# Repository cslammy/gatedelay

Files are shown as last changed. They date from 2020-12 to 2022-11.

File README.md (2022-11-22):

# gatedelay
I needed to delay and extend gate and trigger signals for modular synthesis and logic applications.
Uses Arduino Promini and arduino sketch. 
Allows Delay the entire signal, or just the beginning of the signal while keeping release elements intact.

For more detail please see the blog post here--there are links to earlier posts while the build was being worked out.

https://audiodiwhy.blogspot.com/2019/12/gate-delay-part-iii-works.html

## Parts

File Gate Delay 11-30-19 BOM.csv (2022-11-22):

Part | Value | Device | Package | Description | POPULARITY | SPICEPREFIX | TP_SIGNAL_NAME | Column1
78L05 | 5V | 78LXX | 78LXX | VOLTAGE REGULATOR
C3 | 10uF | CPOL-USE2.5-6 | E2,5-6 | POLARIZED CAPACITOR, American symbol
C4 | 47uF | CPOL-USE2.5-7 | E2,5-7 | POLARIZED CAPACITOR, American symbol
D1 | 1N5404 | 1N4148DO35-10 | DO35-10 | DIODE | 21
D3 |  | WIREPAD2,15/1,0 | 2,15/1,0 | Wire PAD connect wire on PCB | 2
D4 | 4148 | 1N4148DO35-7 | DO35-7 | DIODE | 58
D5 |  | WIREPAD2,15/1,0 | 2,15/1,0 | Wire PAD connect wire on PCB | 2
D6 | NZX5V1 | ZENER.2 | DO41-2
D7 | NZX5V1 | ZENER.2 | DO41-2
DELAYCV |  | 35RAPC2AV | 35RAPCVAV | Switchcraft 35RAPC2AV jack
DELAYLED |  | LED3MM | LED3MM | LED
DELAYPOT | 100K | POTS9MM_VERT | 9MM_VERT
DLYCV_CHK |  | 3,17/1,3 | 3,17/1,3 | THROUGH-HOLE PAD | 3
DOUT |  | 35RAPC2AV | 35RAPCVAV | Switchcraft 35RAPC2AV jack
GATEIN |  | 35RAPC2AV | 35RAPCVAV | Switchcraft 35RAPC2AV jack
GATEINLED |  | LED3MM | LED3MM | LED
IC1 | TL072D | TL072D | SO08 | OP AMP
IC2 | TL072_SMD | TL072_SMD | SO08 | Generic Dual Op Amp
LENGTHCV |  | 35RAPC2AV | 35RAPCVAV | Switchcraft 35RAPC2AV jack
LENGTHPOT | 100K | POTS9MM_VERT | 9MM_VERT
R1 | 10K | R-US_0204/5 | 0204/5 | RESISTOR, American symbol | 18 | R
R2 | 10K' | R-US_0204/5 | 0204/5 | RESISTOR, American symbol | 18 | R
R3 | 10K | R-US_0204/5 | 0204/5 | RESISTOR, American symbol | 18 | R
R4 | 10K | R-US_0204/5 | 0204/5 | RESISTOR, American symbol | 18 | R
R5 | 10k | R-US_0207/10 | 0207/10 | RESISTOR, American symbol
R6 | 10k | R-US_0204/5 | 0204/5 | RESISTOR, American symbol
R7 | 1K | R-US_0207/7 | 0207/7 | RESISTOR, American symbol
R8 | 4.7K | R-US_0204/5 | 0204/5 | RESISTOR, American symbol | 18 | R
R9 | 10K | R-US_0204/5 | 0204/5 | RESISTOR, American symbol | 18 | R
R10 | 10K' | R-US_0204/5 | 0204/5 | RESISTOR, American symbol | 18 | R
R11 | 10K | R-US_0204/5 | 0204/5 | RESISTOR, American symbol | 18 | R
R12 | 10K | R-US_0204/5 | 0204/5 | RESISTOR, American symbol | 18 | R
R13 | 1K | R-US_0204/7 | 0204/7 | RESISTOR, American symbol
R14 | 4.7K | R-US_0204/5 | 0204/5 | RESISTOR, American symbol | 18 | R
R16 | 1K | R-US_0204/7 | 0204/7 | RESISTOR, American symbol
R17 | 1K | R-US_0204/7 | 0204/7 | RESISTOR, American symbol
R18 | 1K | R-US_0207/15 | 0207/15 | RESISTOR, American symbol | 0 | R
S1 | . | ALCOSWTT11 | ALCOSWTT11 | TINY SWITCH ON - MOM
S2 | . | ALCOSWTT11 | ALCOSWTT11 | TINY SWITCH ON - MOM
T1 | 2N3904 | 2N3904 | TO92 | NPN TRANSISTOR | 27
T2 | 2N3904 | 2N3904 | TO92 | NPN TRANSISTOR | 27
T5 | 2N3904 | 2N3904 | TO92 | NPN TRANSISTOR | 27
T6 | 2N3904 | 2N3904 | TO92 | NPN TRANSISTOR | 27
U$1 | PRO-MINI | PRO-MINI | PRO-MINI | Arduion Pro Mini Clone V1.0

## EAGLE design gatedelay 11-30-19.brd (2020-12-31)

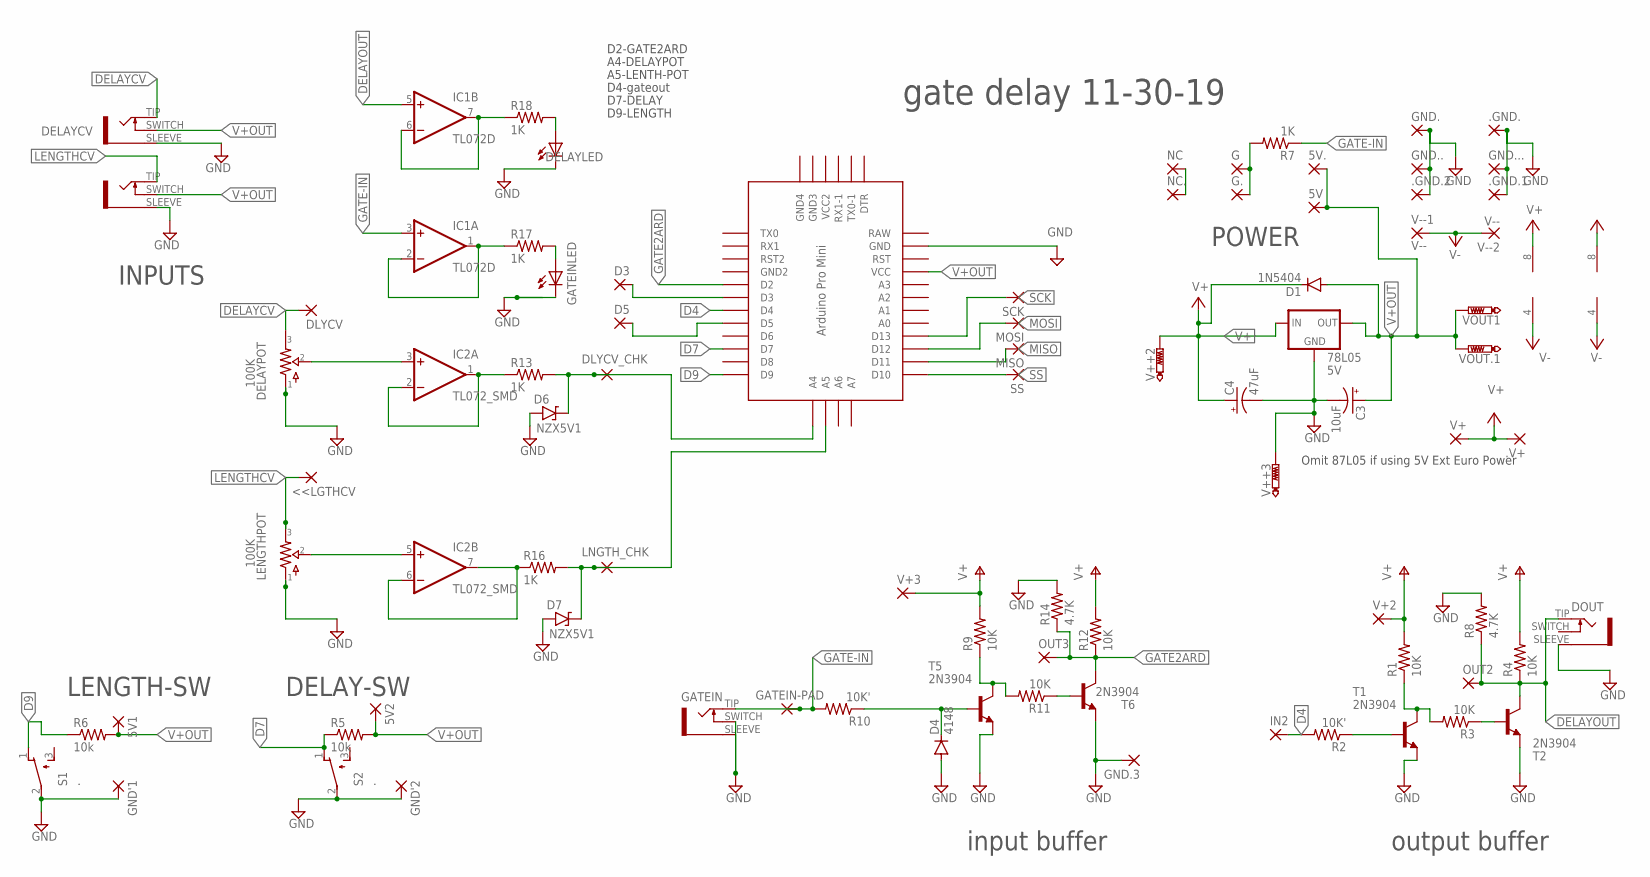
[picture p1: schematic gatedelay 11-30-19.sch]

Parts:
5V, 5V., .GND., .GND.1, .GND.2, .V+: 1,6/0,8
5V1, 5V2: WIREPAD2,54/0,9; 2,54/0,9
78L05: 5V; 78LXX
<<LGTHCV: 3,17/1,3
C3: 10uF; E2,5-6
C4: 47uF; E2,5-7
D1: 1N5404; DO35-10
D3, D5: WIREPAD2,15/1,0; 2,15/1,0
D4: 4148; DO35-7
D6, D7: NZX5V1; DO41-2
DELAYCV: 35RAPC2AV; 35RAPCVAV
DELAYLED: LED3MM
DELAYPOT: 100K; 9MM_VERT
DLYCV: WIREPAD1,6/0,9; 1,6/0,9
DLYCV_CHK: 3,17/1,3
DOUT: 35RAPC2AV; 35RAPCVAV
G, G.: 1,6/0,8
GATEIN: 35RAPC2AV; 35RAPCVAV
GATEIN-PAD: WIREPAD1,6/0,9; 1,6/0,9
GATEINLED: LED3MM
GND'1, GND'2: WIREPAD2,54/0,9; 2,54/0,9
GND., GND.., GND...: 1,6/0,8
GND.3: WIREPAD1,6/0,9; 1,6/0,9
IC1: TL072D; SO08
IC2: TL072_SMD; SO08
IN2: WIREPAD1,6/0,9; 1,6/0,9
LENGTHCV: 35RAPC2AV; 35RAPCVAV
LENGTHPOT: 100K; 9MM_VERT
LNGTH_CHK: 3,17/1,3
MISO: WIREPAD1,6/0,9; 1,6/0,9
MOSI: WIREPAD1,6/0,9; 1,6/0,9
NC, NC.: 1,6/0,8
OUT2, OUT3: WIREPAD1,6/0,9; 1,6/0,9
R1, R3, R4, R9, R11, R12: 10K; 0204/5
R2, R10: 10K'; 0204/5
R5: 10k; 0207/10
R6: 10k; 0204/5
R7: 1K; 0207/7
R8, R14: 4.7K; 0204/5
R13, R16, R17: 1K; 0204/7
R18: 1K; 0207/15
S1, S2: .; ALCOSWTT11
SCK: WIREPAD1,6/0,9; 1,6/0,9
SS: WIREPAD1,6/0,9; 1,6/0,9
T1, T2, T5, T6: 2N3904; TO92
U$1: PRO-MINI
V+: 1,6/0,8
V+2, V+3: WIREPAD1,6/0,9; 1,6/0,9
V++2, V++3: PTR1PAD1-13Y; P1-13Y
V--1, V--2: V--; 1,6/0,8
VOUT1, VOUT.1: PTR1PAD1-13Y; P1-13Y

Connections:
D4: IN2.1, R2.2, U$1.D4
D7: R5.1, S2.1 (O), U$1.D7
D9: R6.1, S1.1 (O), U$1.D9
DELAYCV: DELAYCV.TIP (2), DELAYPOT.3, DLYCV.1
DELAYOUT: DOUT.TIP (2), IC1.5 (+IN), OUT2.1, R4.1, R8.1, T2.1 (C)
GATE2ARD: OUT3.1, R12.1, R14.1, T6.1 (C), U$1.D2
GATE-IN: GATEIN.TIP (2), GATEIN-PAD.1, IC1.3 (+IN), R7.1, R10.2
GND: 78L05.GND, .GND..1, .GND.1.1, .GND.2.1, C3.-, C4.-, D4.A, D6.A, D7.A, DELAYCV.SLEEVE (1), DELAYLED.K (C), DELAYPOT.1, DOUT.SLEEVE (1), GATEIN.SLEEVE (1), GATEIN.SWITCH (3), GATEINLED.K (C), GND'1.1, GND'2.1, GND..1, GND.3.1, GND...1, GND....1, LENGTHCV.SLEEVE (1), LENGTHPOT.1, R8.2, R14.2, S1.2, S2.2, T1.3 (E), T2.3 (E), T5.3 (E), T6.3 (E), U$1.GND, V++3.TP
LENGTHCV: <<LGTHCV.1, LENGTHCV.TIP (2), LENGTHPOT.3
MISO: MISO.1, U$1.D11
MOSI: MOSI.1, U$1.D12
unnamed: D5.1, U$1.D5
unnamed: R2.1, T1.2 (B)
unnamed: R1.1, R3.2, T1.1 (C)
unnamed: R3.1, T2.2 (B)
unnamed: G.1, G..1, R7.2
unnamed: D3.1, U$1.D3
unnamed: NC.1, NC..1
unnamed: D4.C, R10.1, T5.2 (B)
unnamed: R9.1, R11.2, T5.1 (C)
unnamed: R11.1, T6.2 (B)
unnamed: D6.C, DLYCV_CHK.1, R13.2, U$1.A4
unnamed: DELAYPOT.2, IC2.3 (+IN)
unnamed: IC2.1 (OUT), IC2.2 (-IN), R13.1
unnamed: IC2.5 (+IN), LENGTHPOT.2
unnamed: IC2.6 (-IN), IC2.7 (OUT), R16.1
unnamed: D7.C, LNGTH_CHK.1, R16.2, U$1.A5
unnamed: GATEINLED.A, R17.2
unnamed: IC1.1 (OUT), IC1.2 (-IN), R17.1
unnamed: IC1.6 (-IN), IC1.7 (OUT), R18.1
unnamed: DELAYLED.A, R18.2
RAW: U$1.RAW
SCK: SCK.1, U$1.D13
SS: SS.1, U$1.D10
V+: 78L05.IN, .V+.1, C4.+, D1.C, IC1.8 (V+), IC2.8 (V+), R1.2, R4.2, R9.2, R12.2, V+.1, V+2.1, V+3.1, V++2.TP
V+OUT: 5V.1, 5V1.1, 5V2.1, 5V..1, 78L05.OUT, C3.+, D1.A, DELAYCV.SWITCH (3), LENGTHCV.SWITCH (3), R5.2, R6.2, U$1.VCC, VOUT1.TP, VOUT.1.TP
V-: IC1.4 (V-), IC2.4 (V-), V--1.1, V--2.1

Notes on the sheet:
POWER
DELAY-SW
LENGTH-SW
gate delay 11-30-19
output buffer
input buffer
D7-DELAY
D9-LENGTH
D4-gateout
A5-LENTH-POT
A4-DELAYPOT
D2-GATE2ARD
INPUTS
Omit 87L05 if using 5V Ext Euro Power

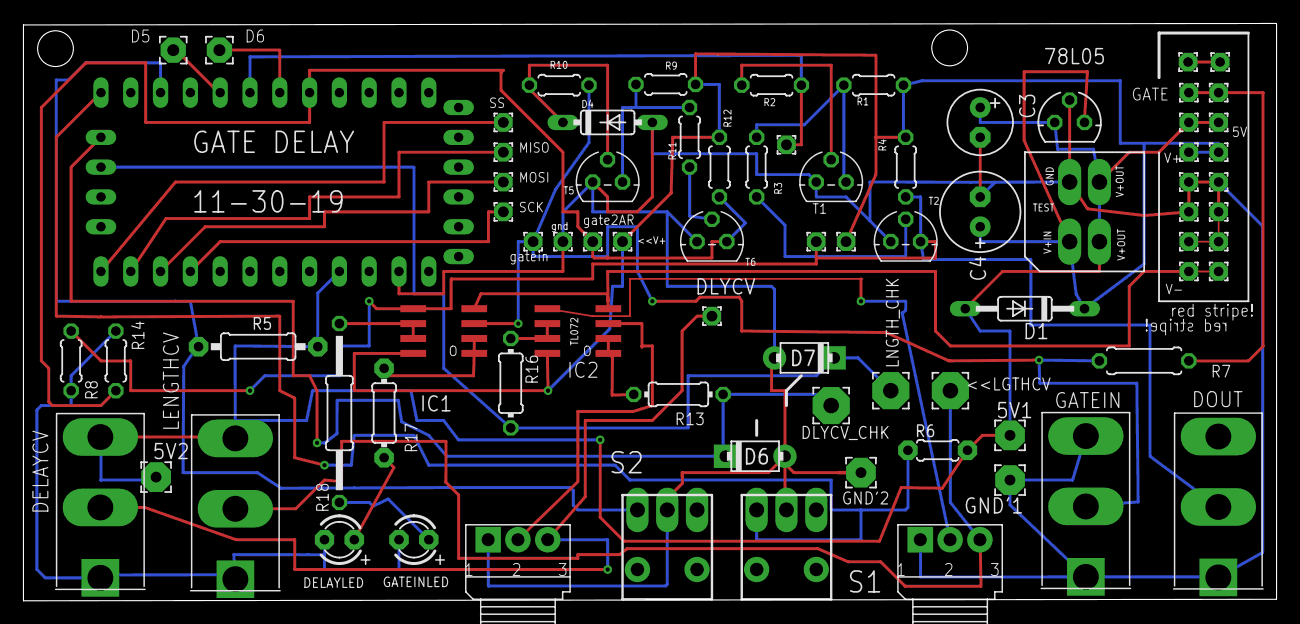
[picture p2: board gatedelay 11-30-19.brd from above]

Board: 2 copper layers, 106.8 x 49.2 mm, 82 parts (0 on the bottom side), 36 nets.

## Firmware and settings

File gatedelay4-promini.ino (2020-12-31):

const int GATEIN_PIN = 9;
const int GATESTATUS_PIN = 13;
int LENGTH_PIN = A0;
int DELAY_PIN = A1;

int CYCLE = 0;

int SKIP_DELAY = 0;
int SKIP_LENGTH = 0;

const int GATEOUT_PIN = 5;
const int EOGL_PIN = 2;  // length pot
const int EOGD_PIN = 3;   // delay pot

boolean EOGL_SW = HIGH;
boolean EOGD_SW = HIGH;
boolean GATEIN = LOW;
boolean GATEIN2 = LOW;
boolean GATEIN3 = LOW;
boolean GATESTATUS = LOW;
int x = 0;

unsigned long EOGL = 0;  //value of EOGL pot must be UL compared to time
unsigned long EOGD = 0;  // value of EOGD pot, ditto.


//timer variables
unsigned long begin_delay=0;
unsigned long begin_length=0;
unsigned long current_delay = 0;
unsigned long current_length = 0;
unsigned long test_delay = 0;
unsigned long test_length =0;

void setup() {
  // put your setup code here, to run once:
pinMode(GATEIN_PIN,INPUT);
pinMode(DELAY_PIN,INPUT);
pinMode(LENGTH_PIN,INPUT);
pinMode(EOGL_PIN,INPUT);
pinMode(EOGD_PIN,INPUT);



pinMode(GATESTATUS_PIN,OUTPUT);
pinMode(GATEOUT_PIN,OUTPUT);

digitalWrite(GATEOUT_PIN,LOW);

Serial.begin(9600);


} // end setup





void getstatus() {
    
    GATESTATUS = digitalRead(GATEIN_PIN);
    if (GATESTATUS == HIGH)
      {
        digitalWrite(GATESTATUS_PIN,HIGH);
      }
     else
      { 
        digitalWrite(GATESTATUS_PIN,LOW); 
      }
}  // end getstatus ()




void loop() 

{
//Serial.println("*****BEGINNING MAIN LOOP!*****")  ;



GATEIN = digitalRead(GATEIN_PIN);
delay(3);

//Serial.println("==========================CYCLE===========================");
//Serial.println(CYCLE);

if (GATEIN == LOW)
   {
    CYCLE = 0;

   }
   
if ((GATEIN == HIGH) && (CYCLE < 2 ))

      {
      CYCLE++;
      
      getstatus();
      begin_delay = millis();
      EOGD = 100;
      test_delay = 0;


/*
           Serial.println("OUTSIDE EOGD WHILE");
           Serial.println ("OUTSIDE test_delay is:");
           Serial.println (test_delay);
           Serial.println ("OUTSIDE EOGD is:");
           Serial.println (EOGD);
*/
   
      while ((EOGD > test_delay) && (SKIP_DELAY == 0)) 
           {
            getstatus();
           
            digitalWrite(GATEOUT_PIN,LOW);
            EOGD = (analogRead(DELAY_PIN) * 10);
            delay(3);
            current_delay = millis();
            test_delay = current_delay - begin_delay;    
      

     /*

           Serial.println("****INSIDE EOGD WHILE****");
           Serial.println ("INSIDE testdelay value is:");
           Serial.println (test_delay);
           Serial.println ("INSIDE EODG value is:");
           Serial.println (EOGD);
*/
           
  

          // check for EOGD_SW high and gate low.If that's the case skip rest of delay cycle.
          GATEIN2 = digitalRead(GATEIN_PIN);
          EOGD_SW = digitalRead(EOGD_PIN);


          if ((EOGD_SW == HIGH) && (SKIP_DELAY == 0) && (GATEIN2 == LOW))
              { 
                Serial.println("you are in SKIP delay");
               SKIP_DELAY = 5;
              }


          Serial.print("EOGD_SW value:  ");
          Serial.println(EOGD);
          Serial.print("SKIP_DELAY value:  ");
          Serial.println(SKIP_DELAY);
          Serial.print("GATEIN2 value:  ");
          Serial.println(GATEIN2);
          
    
                
           } // end EODG while 
         

         digitalWrite(GATEOUT_PIN,HIGH);    
           
 //DELAY IS OVER, GATE IS HIGH, NOW MOVE ON TO LENGTH  
          
          
          begin_length = millis();
          EOGL = 100;
          test_length = 0;
  
           /*
           Serial.println("OUTSIDE EOGL WHILE");
           Serial.println ("testlength is:");
           Serial.println (test_length);
           Serial.println ("EOGL is:");
           Serial.println (EOGL);
          */
 while ((EOGL > test_length)  && (SKIP_LENGTH == 0))
           {
            getstatus();
             EOGL = (analogRead(LENGTH_PIN) * 10);
            delay(3);   
             current_length = millis();      
            test_length = current_length - begin_length;        

           /*
           Serial.println ("INSIDE testlength is:");
           Serial.println (test_length);
           Serial.println ("INSIDE EOGL is:");
           Serial.println (EOGL);
           */
             // check status of EOGL switch and GATE  
  
        
// check for EOGL_SW high and gate low.If that's the case skip rest of length cycle.
          GATEIN3 = digitalRead(GATEIN_PIN);
          EOGL_SW = digitalRead(EOGL_PIN);
          if ((EOGL_SW == HIGH) && (SKIP_LENGTH == 0) && (GATEIN3 == LOW))
              { 
               SKIP_LENGTH = 5;
              Serial.println("You are in SKIP_LENGTH");
              }
           

             }           //end EOGL while

              digitalWrite(GATEOUT_PIN,LOW);
              delay(3);
              getstatus();
              delay(3);


      }    // end main loop IF 
         else
         {
   //      Serial.println("----------------GATE IS OFF---------------");
         digitalWrite(GATEOUT_PIN,LOW);
         
         // once it's off, stay off dammit!
         
         CYCLE ++;
         if (CYCLE > 6)
         {
          CYCLE = 2;
         }
         }

SKIP_DELAY = 0;
SKIP_LENGTH = 0;
GATEIN2 = HIGH;
GATEIN3 = HIGH;
        
} // end main loop
